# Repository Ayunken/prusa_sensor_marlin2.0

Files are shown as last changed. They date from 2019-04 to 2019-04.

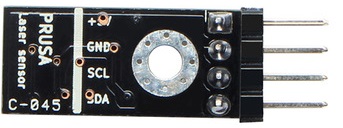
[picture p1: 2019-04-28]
PAT9125.jpg

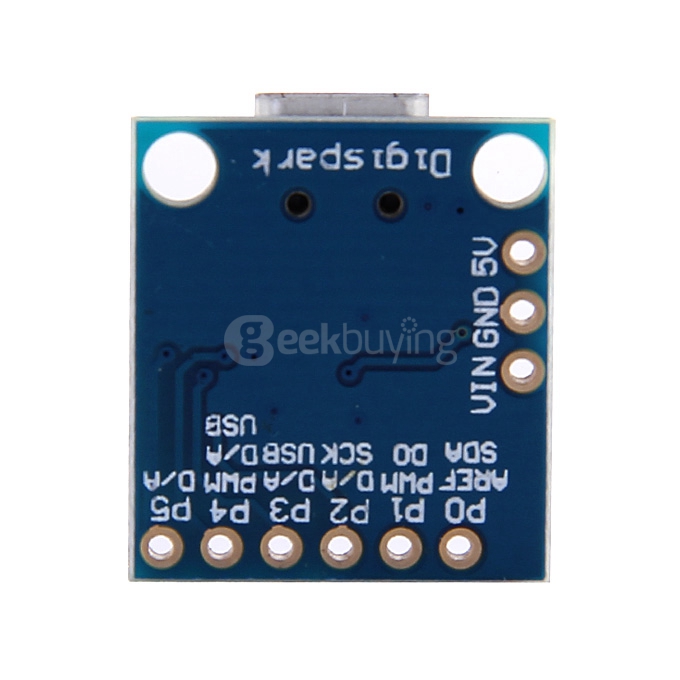
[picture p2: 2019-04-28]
digispark.jpg

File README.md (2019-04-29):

# Implementación del sensor de movimiento de filamento de Prusa, el PAT9125, en Marlin 2.0.
Hace unos meses adquirí un modulo PAT9125 pensando en poder incorporar este novedoso sensor láser de la Prusa en mi P3Steel donde usaba Marlin 1.1.9.

Estuve revisando el código del firmware de prusa y no conozco tanto Marlin como para incorporar directamente el sensor usando las librerías de Prusa, más usando I2C como protocolo, que es el que usa este módulo (SDA/SCL).

Pero después descubrí que Marlin 2.0 (aunque en la release bug-fix) incorpora una nueva característica mediante la cual se puede controlar los atascos o falta de filamento en base al movimiento del mismo, mediante un encoder.

Se me ocurrio pues usar un modulo Attiny85 que hiciera de interfaz entre el sensor y mi electrónica RAMPS1.4+Mega2560 que corre Marlin 2.0
El Attiny85 recibe los datos del movimiento del sensor (coordenada y) mediante I2C y, siempre que ve cambios en dicho valor, envía pulsos (HIGH/LOW) hacia al pin de deteccion de filamento (normalmente el puerto D4). Además como el módulo Attiny tiene un led 'bultin' que se activa mediante la salida 1, tambén lo enciendo a la vez que el pulso de encoder, lo que sirve de monitor

Encontré en Thingiverse un soporte para el sensor de Prusa https://www.thingiverse.com/thing:3387643, bastante elegante y mínimo, por lo que opté por usarlo y dejar el módulo Attiny separado en otra cajita, que coloqué encima de la caja de la electrónica,  dejando un orificio para el led de actividad. 

Sin embargo el soporte tuve que modificarlo porque el filamento pasaba demasiado cerca del láser, prácticamente tocando, y no detectaba bien, y modifqué el soprote separando el orificio 2 milímetros del láser, con lo que detectaba perfectamente. He probado con filamento negro, blanco y rojo y funciona perfectamente. Me falta probar con transparentes o translúcidos, a ver que tal. Aunque siempre se puede desconectara desde el menú del lcd si algún filamento da problemas.

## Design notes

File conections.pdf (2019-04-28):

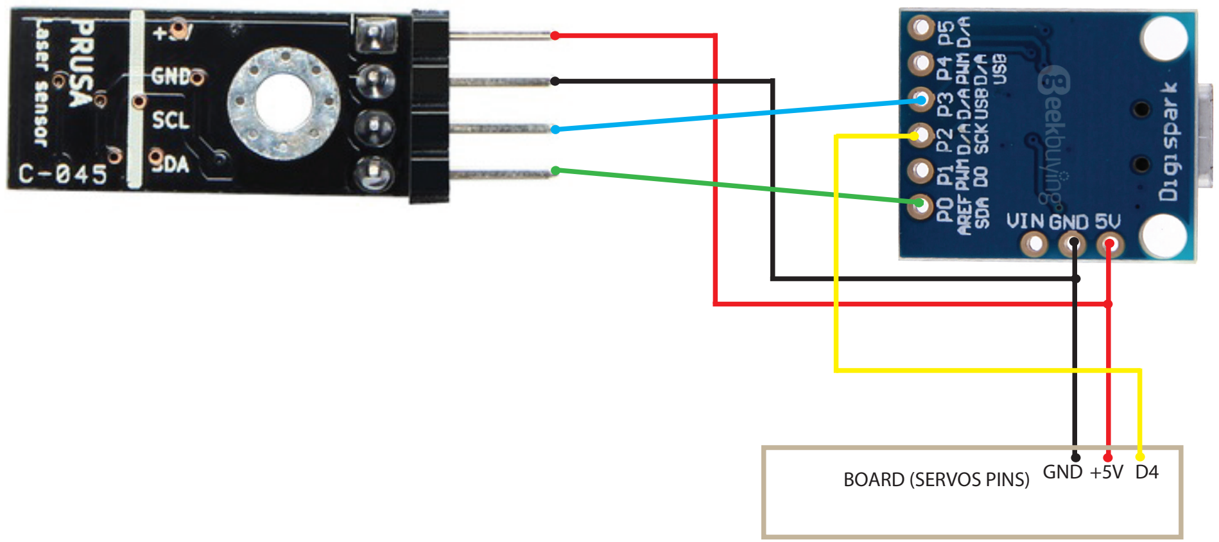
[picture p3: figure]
BOARD (SERVOS PINS) GND +5V D4

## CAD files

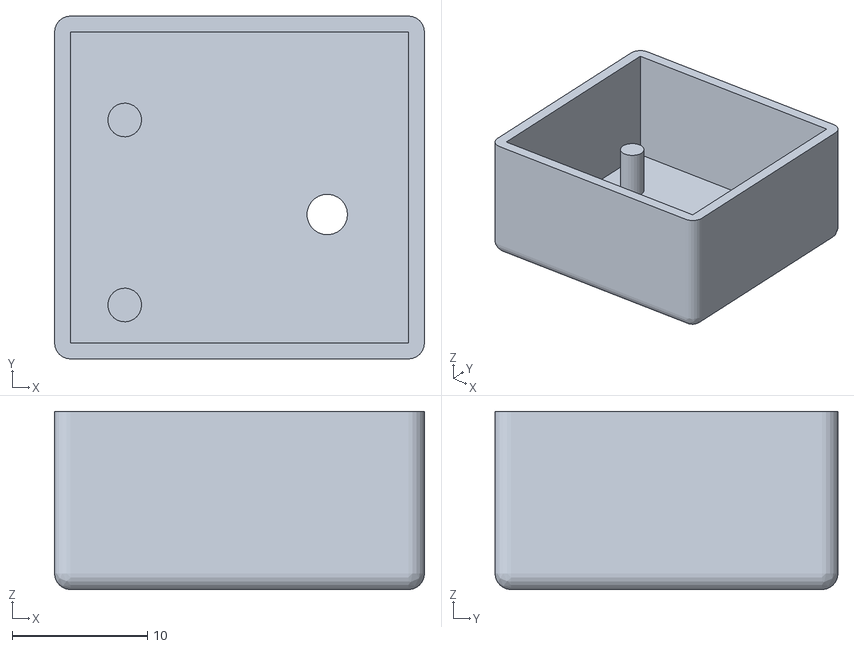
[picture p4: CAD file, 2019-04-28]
attiny_case.stl
27.4 x 25.4 x 13.2

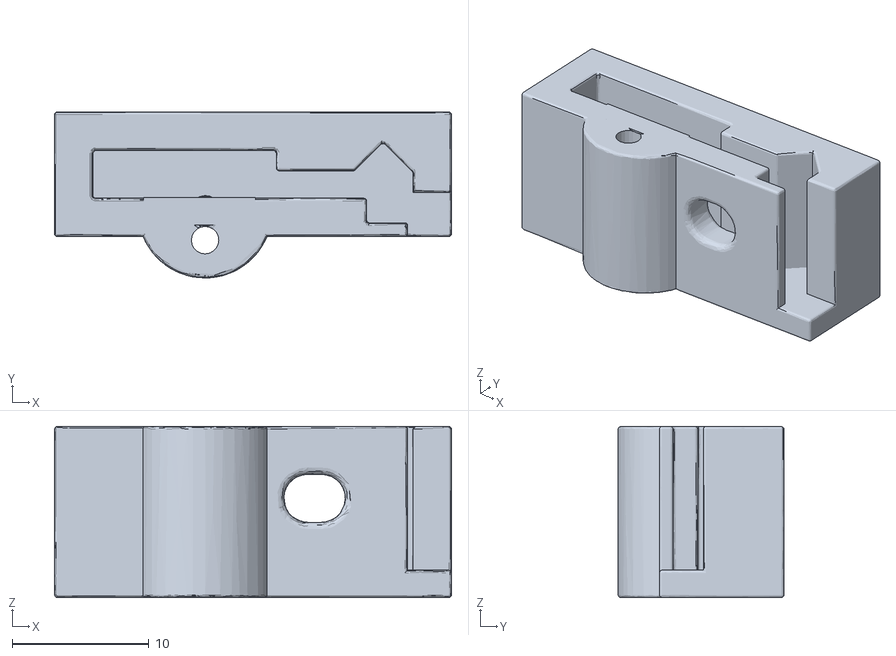
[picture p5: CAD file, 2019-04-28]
printed parts/Prusa Sensor v2.stl
29.0 x 12.1 x 12.5

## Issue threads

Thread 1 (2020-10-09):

sensor does not work

Guga1310, 2020-10-09:
good morning friend i followed your step by step i'm using a skr 1.4 and i couldn't get the sensor to work.

Deema35, 2021-05-07:
I think I am too late but conections.pdf has mistake. You need swap P3 and P2.

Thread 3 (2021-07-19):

I think I am too late but conections.pdf has mistake. You need swap P3 and P2.

dragsterbox, 2021-07-19:
I think I am too late but conections.pdf has mistake. You need swap P3 and P2.

_Originally posted by @Deema35 in https://github.com/Ayunken/prusa_sensor_marlin2.0/issues/1#issuecomment-834518863_

Hi, I swapped the pins but it is still not working.

dragsterbox, 2021-08-02:
Do you have any plans to publish your code or update the package ? I have tried to swap P3 and P2 as suggested but now the sensor is always triggered.

Deema35, 2021-08-03:
This is my fork https://github.com/Deema35/prusa_sensor_marlin2.0.

dragsterbox, 2021-08-04:
> This is my fork https://github.com/Deema35/prusa_sensor_marlin2.0.

Thank you Deema35.

I uploaded your firmware and connected the devices as per the diagram below but it is still not triggering. Marlin firmware has also been updated

Can you help and let me know if I missed something ?

 Using this device: https://www.aliexpress.com/item/4000098995446.html?spm=a2g0s.9042311.0.0.27424c4d7HSq5O

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

Deema35, 2021-08-04:
Is led blinking or not? Because this can be sensor malfunction. If you have arduino uno or nano try with it and find out, funktion pat9125.Get_delta_x() get something or not.

dragsterbox, 2021-08-19:
> Is led blinking or not? Because this can be sensor malfunction. If you have arduino uno or nano try with it and find out, funktion pat9125.Get_delta_x() get something or not.

Hi, I finally managed to get an arduino one for testing but I am having this message now when I define Uno

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

Deema35, 2021-08-20:
Hi this is my fault. Variable yy stay from last code. Just erase it.

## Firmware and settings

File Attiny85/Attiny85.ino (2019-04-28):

/**
  Firmware para Attiny85 (Digispark 16Mhz)
  Lee la posicion Y del sensor PAT9125 y si hay diferencia con el anterior valor
  desencadena un pulso en el pin out y enciende el builtin LED
  pin I2S: 0 SDA, 2 CLK
  pint out: 3
  establecer trgtime con el valor en ms de la duración del pulso 
**/


#include "pat9125.h"
/*
void printSerial(const char *fmt, ...)
{
  char tmp[100];
  va_list args;
// Obtenemos la lista de argumentos
  va_start (args, fmt );
  // Escribimos en tmp, con tamaÃƒÂ±o MAX_CADENA, la cadena de formato serÃƒÂ¡ fmt y los
  // argumentos args
  vsnprintf(tmp, 100, fmt, args);
  va_end (args);
  Serial.print(tmp);
 
}*/

#define MCU_AT85  //ATTINY 85
//#define MCU_AUNO //MICRO/UNO

#ifdef MCU_AT85
 int led=1; // builtin led
 int out=3; // output to printer board as encoder
#endif
#ifdef MCU_AUNO
  // UNO
  int led=13; // builtin led
  int out=4; // output to printer board as encoder
#endif*/

long yy=0; // last y value
int ydelta=1; // relativo change in y to trigger
int trgtime=100; // ms duration pulse 
//boolean state; // save last output state

void trigger_pin(){
    #ifdef MCU_AUNO
      Serial.println("TRIGGER");
    #endif  
    digitalWrite(led,HIGH);
    digitalWrite(out,HIGH);
    delay(trgtime);
    digitalWrite(led,LOW);
    digitalWrite(out,LOW);
    delay(100);
    
}

/*
/void swap_pin(){
    state=!state;
    digitalWrite(led,state?HIGH:LOW);
    digitalWrite(out,state?HIGH:LOW);
}
*/
void setup(){ //Marlin_main.cpp
    #ifdef MCU_AUNO
        Serial.begin(9600);  
    #endif    
    //fsensor_autoload_set(true);
    
    pinMode(led,OUTPUT);
    pinMode(out,OUTPUT);
    digitalWrite(led,HIGH);
    
    uint8_t pat9125 = pat9125_init();
    
    for (int i=0;i<2;i++){
    digitalWrite(led,HIGH);
    delay(100);  
    digitalWrite(led,LOW);
    delay(100);  
    }
     
    //Serial.print("PAT9125_init:");
    //Serial.println(pat9125);
    
}

void loop(){
     
     pat9125_update(); //update sensor
     
     if (abs(pat9125_y-yy)>ydelta) 
       {
        #if MCU_AUNO
        Serial.println("x"+String( yy)+" y:" + String( pat9125_y));
        #endif
        yy=pat9125_y;
        trigger_pin();}
     //if (pat9125_y==yy and state==1)
     //     swap_pin();      
     
     //delay(100);
}
    
/*
// MarLlin_main.cpp functions
void manage_inactivity(bool ignore_stepper_queue){
        if (fsensor_check_autoload())
        {
          fsensor_autoload_check_stop();
          Serial.println("No detecto")
      }
      else
      {
        fsensor_autoload_check_stop();
        fsensor_update();
      }
  
}

void process_commands(){ //Marlin_main.cpp
  #ifdef PAT9125
  else if (code_seen("FSENSOR_RECOVER")) { //! FSENSOR_RECOVER
      fsensor_restore_print_and_continue();
    }
  #endif //PAT9125
}

void gcode_M701(){ 
  //Medficion de calidad
   fsensor_oq_meassure_start(40);
  
  /* se carga filamento ....
  
  
        fsensor_oq_meassure_stop();

        if (!fsensor_oq_result())
        {
            Serial.println("Fil. sensor response is poor, disable it?")
            //fsensor_disable(); // para deshabilitar el sensor
        }
  
}
  
	void dcode_9125()
	{
    //debug
  		Serial.println("x=%d y=%d b=%d s=%d\n", pat9125_x, pat9125_y, pat9125_b, pat9125_s);
		
		
	}
 */

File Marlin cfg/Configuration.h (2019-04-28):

// ONLY KEY PARAMETERS TO ENABLE/CONFIGURE. THIS IS NOT A COMPLETE CONFIGURATION.H FILE FOR MARLIN 
/**
 * Filament Runout Sensors
 * Mechanical or opto endstops are used to check for the presence of filament.
 *
 * RAMPS-based boards use SERVO3_PIN for the first runout sensor.
 * For other boards you may need to define FIL_RUNOUT_PIN, FIL_RUNOUT2_PIN, etc.
 * By default the firmware assumes HIGH=FILAMENT PRESENT.
 */
#define FILAMENT_RUNOUT_SENSOR
#if ENABLED(FILAMENT_RUNOUT_SENSOR)
  #define NUM_RUNOUT_SENSORS   1     // Number of sensors, up to one per extruder. Define a FIL_RUNOUT#_PIN for each.
  #define FIL_RUNOUT_INVERTING false // set to true to invert the logic of the sensor.
  #define FIL_RUNOUT_PULLUP          // Use internal pullup for filament runout pins.
  //#define FIL_RUNOUT_PULLDOWN      // Use internal pulldown for filament runout pins.

  // Set one or more commands to execute on filament runout.
  // (After 'M412 H' Marlin will ask the host to handle the process.)
  #define FILAMENT_RUNOUT_SCRIPT "M600"

  // After a runout is detected, continue printing this length of filament
  // before executing the runout script. Useful for a sensor at the end of
  // a feed tube. Requires 4 bytes SRAM per sensor, plus 4 bytes overhead.
  #define FILAMENT_RUNOUT_DISTANCE_MM 25

  #ifdef FILAMENT_RUNOUT_DISTANCE_MM
    // Enable this option to use an encoder disc that toggles the runout pin
    // as the filament moves. (Be sure to set FILAMENT_RUNOUT_DISTANCE_MM
    // large enough to avoid false positives.)
    #define FILAMENT_MOTION_SENSOR
  #endif
#endif
